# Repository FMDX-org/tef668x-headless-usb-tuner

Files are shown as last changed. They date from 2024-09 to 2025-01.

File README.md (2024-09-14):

# TEF668X Headless USB Tuner

USB radio tuner based on STM32F072 MCU and TEF6687 RF receiver with three antenna inputs and digital audio.

Copyright (C) 2024 FMDX.org

You may redistribute and modify this source under the terms of the CERN-OHL-W v2 (see LICENSE file).

# Credits 

- Konrad Kosmatka - HW & FW architecture and development
- Sjef Verhoeven - HW development
- Marek Kraus - HW & FW prototyping
- Marek Farkaš - testing and integration with FM-DX Webserver
- Przemysław Korpas - HW consultation, reviews
- Sebastian Białkowski - HW consultation, reviews

# Firmware

The firmware is available in a separate repository: [FM-DX-Tuner](https://github.com/kkonradpl/FM-DX-Tuner).

Firmware dependencies:
- Board: STM32 MCU Based Boards ([STM32duino](https://github.com/stm32duino)) - download using board manager
- Library: [TinyUSB](https://github.com/hathach/tinyusb) - install manually to the Arduino libraries

During first firmware flashing, short BOOT to 3.3V, plug the USB cable and flash using Arduino IDE (DFU method). Once the firmware is running, it is not necessary to manually short BOOT pin. See [tef-bootloader](https://github.com/kkonradpl/tef-bootloader).

# Audio output

The baseline version of the tuner supports only digital audio over USB. For a regular analog audio line-out, see the [Audiohat for Headless TEF](https://github.com/PE5PVB/Audiohat-Headless-TEF/).

# Important remarks

- TEF6687/V205 (F8705) chip is recommended for the best performance (FMSI, FULL SCAN RDS).
- RF circuits should contain NP0 (C0G) capacitors.
- Only V205 version of TEF668X supports the 55.46667 MHz crystal.
- For a crystal different than 55.46667 MHz, GPIO1 must be pulled to the ground (instead of pull-up).
- All capacitors and resistors are 0603, except R30 and R31 which are 0402.

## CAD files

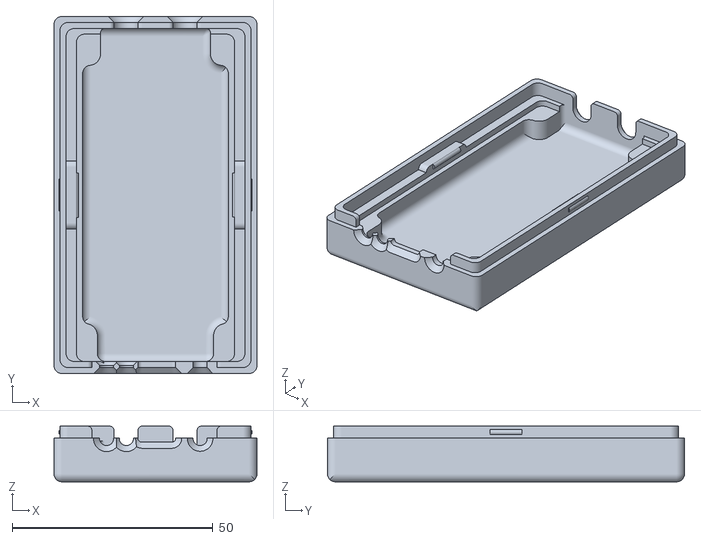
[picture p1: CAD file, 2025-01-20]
3d case/bottom.stl
50.5 x 88.8 x 13.9

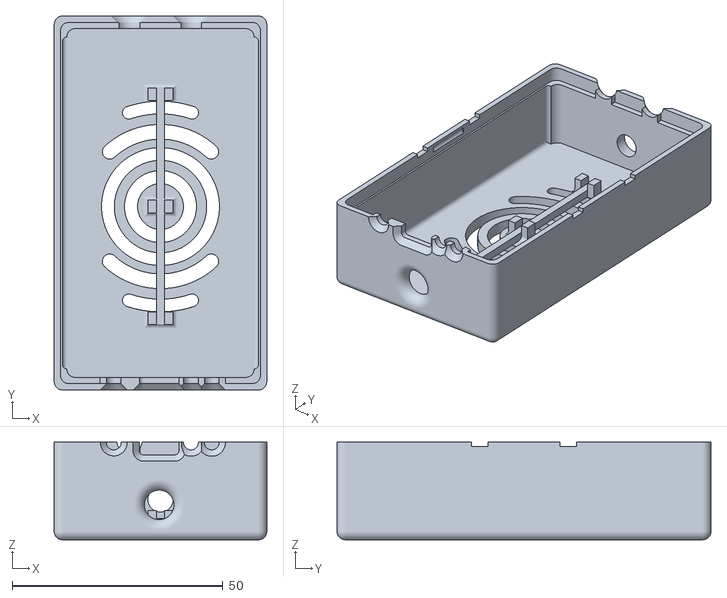
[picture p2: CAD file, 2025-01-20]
3d case/top.stl
50.5 x 88.8 x 23.2

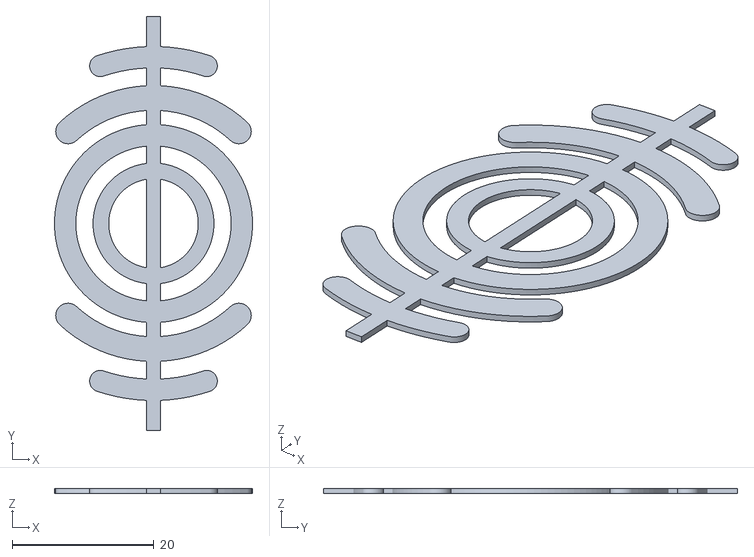
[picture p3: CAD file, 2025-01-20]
3d case/logo.stl
28.0 x 58.5 x 0.66

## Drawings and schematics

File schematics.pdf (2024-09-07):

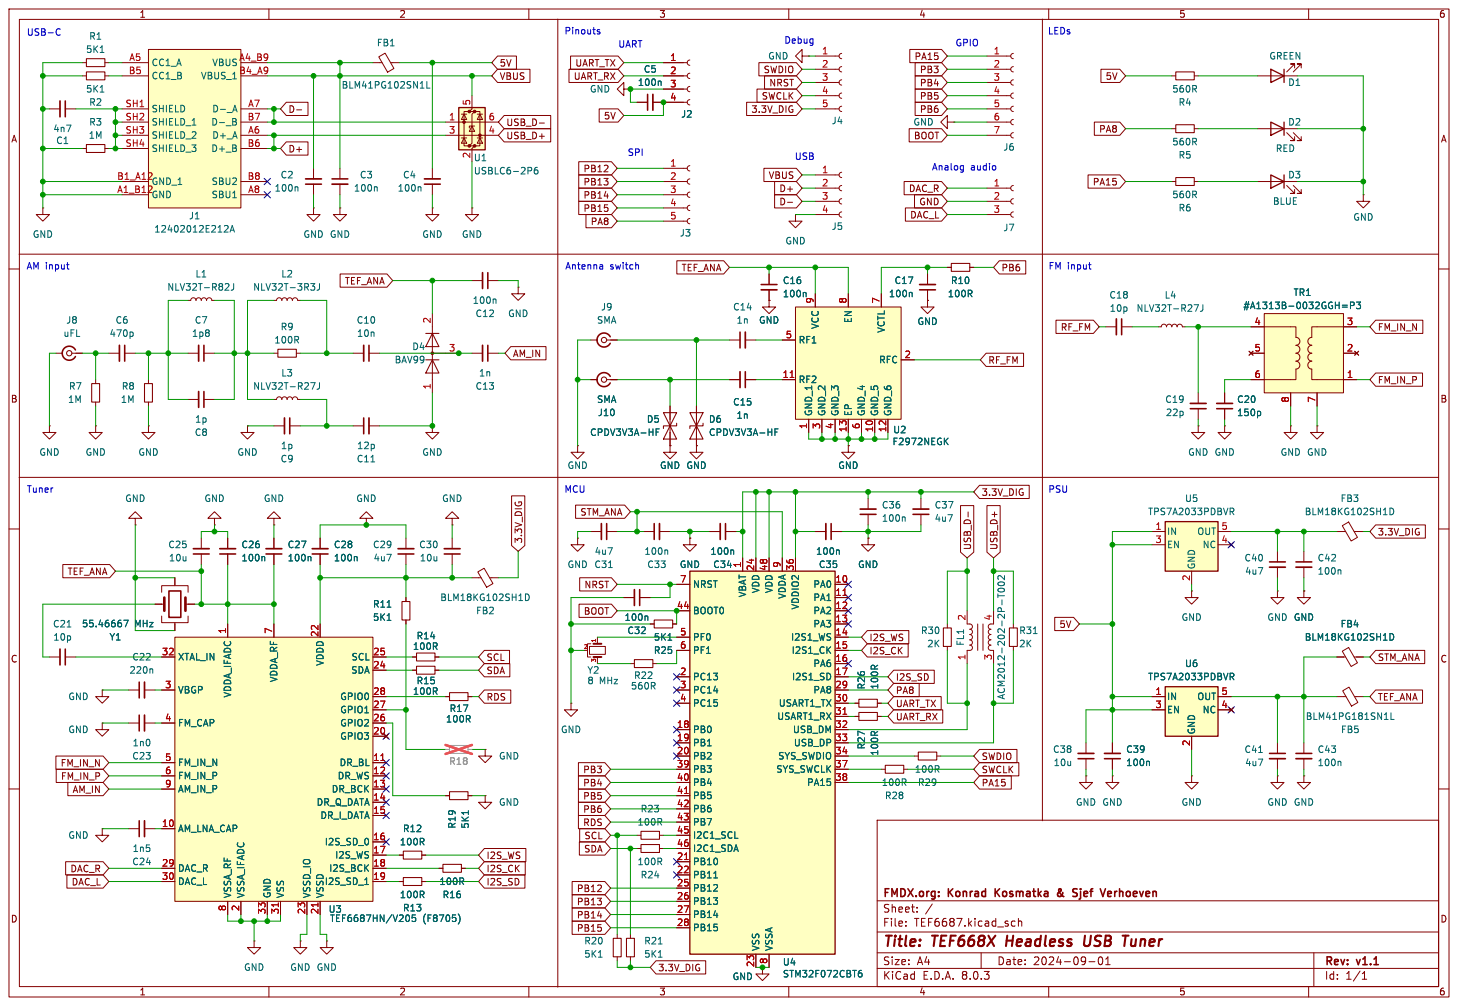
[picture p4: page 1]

2 EN 3 NC 4 OUT 5 U5 TPS7A2033PDBVR GND A1_B12 VBUS A4_B9 CC1_A A5 D+_A A6 D-_A A7 SBU1 A8 GND_1 B1_A12 VBUS_1 B4_A9 CC1_B B5 D+_B B6 D-_B B7 SBU2 B8 SHIELD SH1 SHIELD_1 SH2 SHIELD_2 SH3 SHIELD_3 SH4

2 GPIO3 20 VSSD 21 VDDD 22 VSSD_IO 23 SDA 24 SCL 25 GPIO2 26 GPIO1 27 GPIO0 28 DAC_R 29 VBGP 3 DAC_L 30 VSS 31 XTAL_IN 32 GND 33 FM_CAP 4 FM_IN_P 6 VDDA_RF

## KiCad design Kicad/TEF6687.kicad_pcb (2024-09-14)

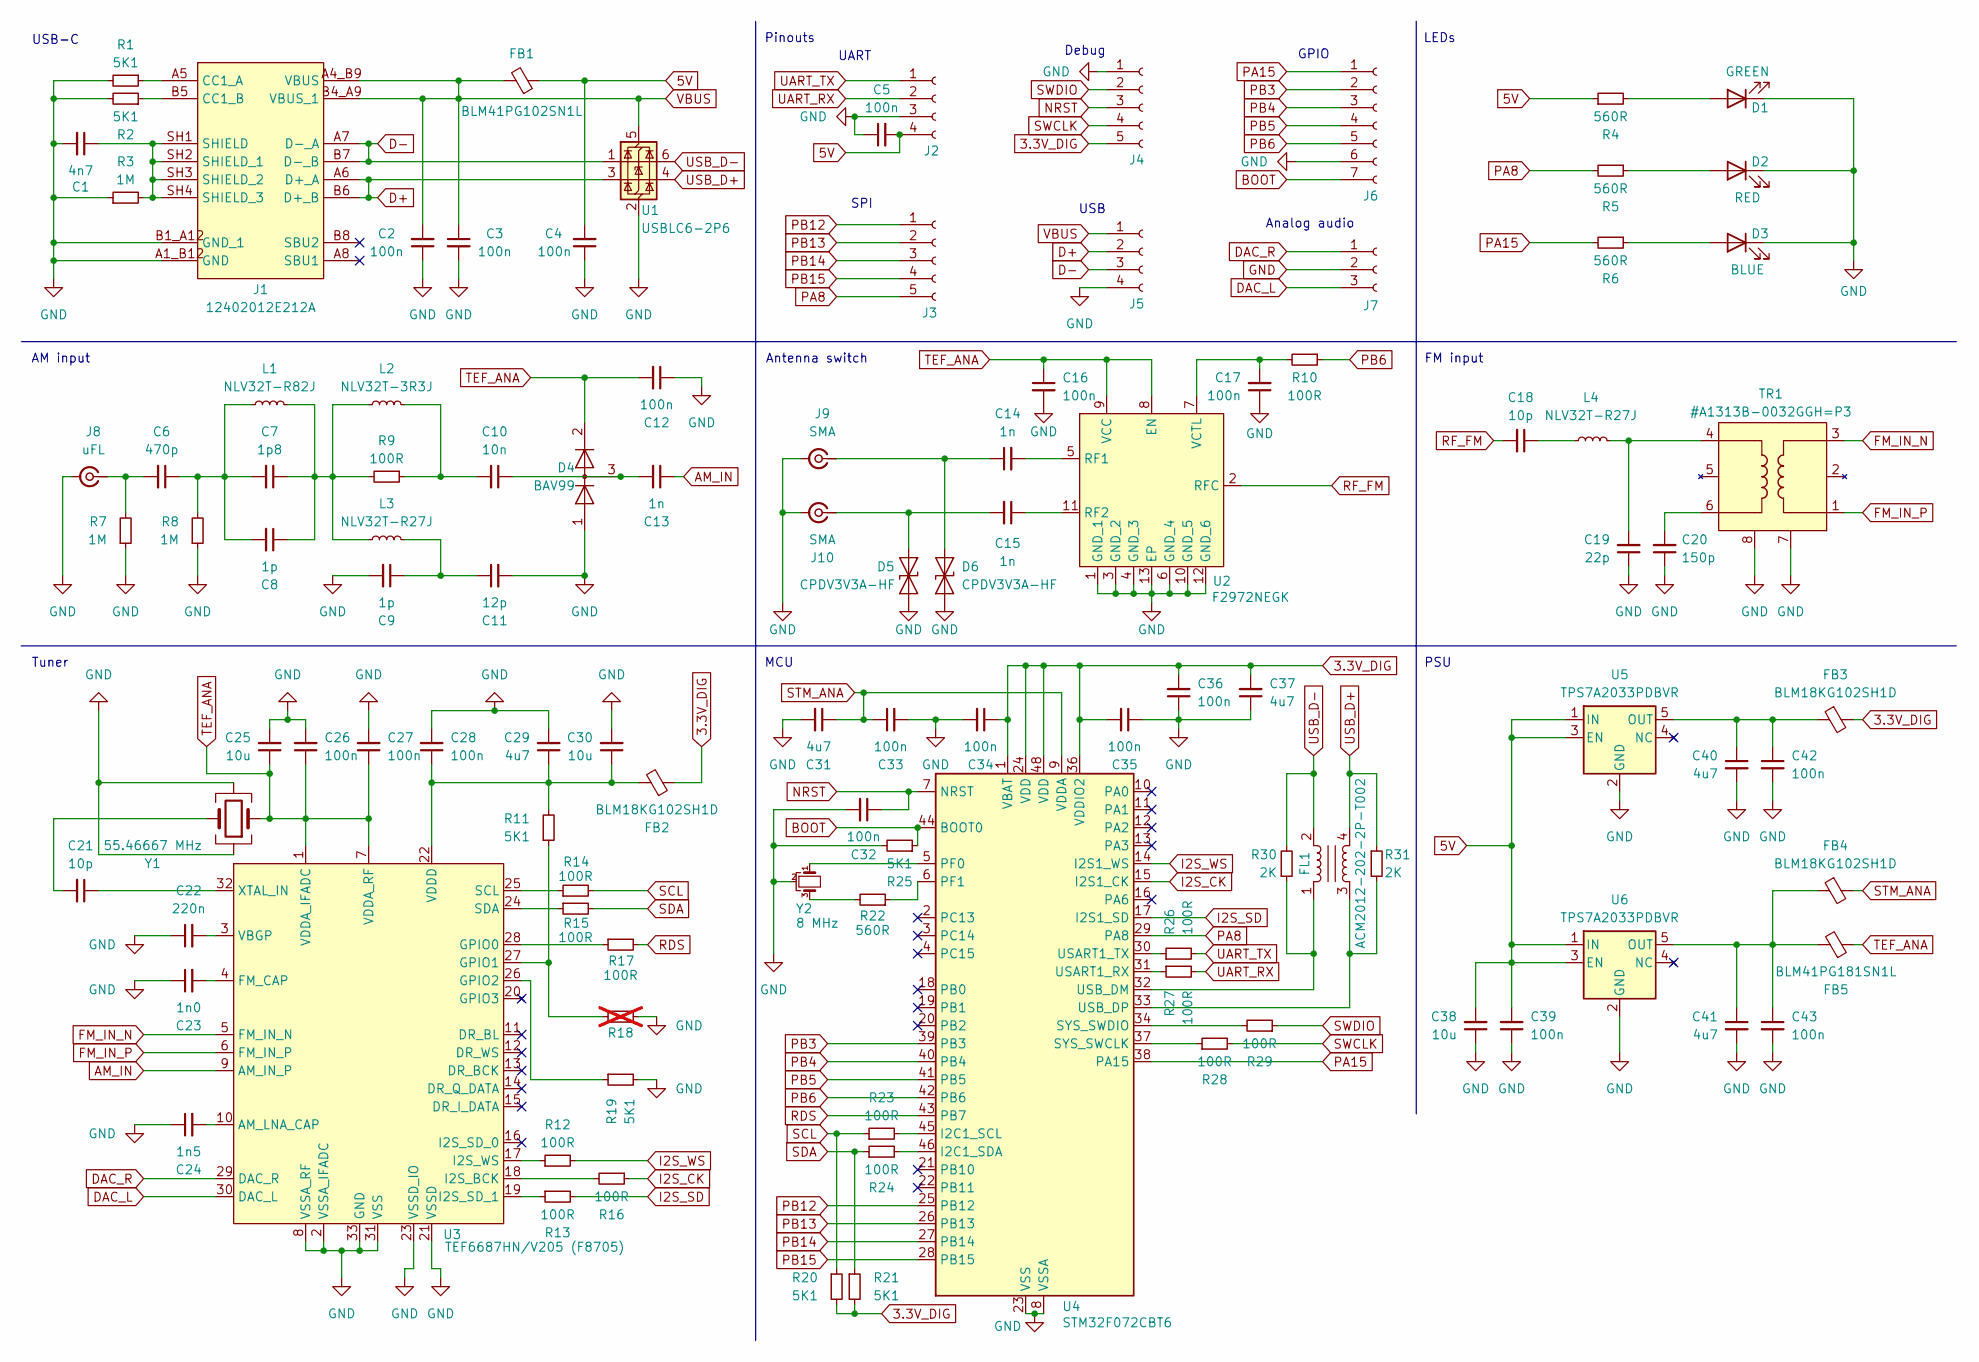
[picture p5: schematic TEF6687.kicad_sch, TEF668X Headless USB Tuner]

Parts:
C1: 4n7; C_0603_1608Metric
C2, C3, C4, C5, C12, C16, C17, C26, C27, C28, C32, C33, C34, C35, C36, C39, C42, C43: 100n; C_0603_1608Metric
C6: 470p; C_0603_1608Metric
C7: 1p8; C_0603_1608Metric
C8, C9: 1p; C_0603_1608Metric
C10: 10n; C_0603_1608Metric
C11: 12p; C_0603_1608Metric
C13, C14, C15: 1n; C_0603_1608Metric
C18, C21: 10p; C_0603_1608Metric
C19: 22p; C_0603_1608Metric
C20: 150p; C_0603_1608Metric
C22: 220n; C_0603_1608Metric
C23: 1n0; C_0603_1608Metric
C24: 1n5; C_0603_1608Metric
C25, C30, C38: 10u; C_0603_1608Metric
C29, C31, C37, C40, C41: 4u7; C_0603_1608Metric
D1: GREEN; LED_D1.8mm_W3.3mm_H2.4mm
D2: RED; LED_D1.8mm_W3.3mm_H2.4mm
D3: BLUE; LED_D1.8mm_W3.3mm_H2.4mm
D4: BAV99; SOT-23
D5, D6: CPDV3V3A-HF; D_SOD-323_HandSoldering
FB1: BLM41PG102SN1L; L_1806_4516Metric
FB2, FB3, FB4: BLM18KG102SH1D; L_0603_1608Metric
FB5: BLM41PG181SN1L; L_1806_4516Metric
FL1: ACM2012-202-2P-T002; USB_Filter_0805
J1: 12402012E212A
J2: 1x4; PinSocket_1x04_P2.54mm_Vertical
J3, J4: 1x5; PinSocket_1x05_P2.54mm_Vertical
J5: 1x4; JST_PH_S4B-PH-SM4-TB_1x04-1MP_P2.00mm_Horizontal
J6: 1x7; PinSocket_1x07_P2.54mm_Vertical
J7: 1x3; PinSocket_1x03_P2.54mm_Vertical
J8: uFL; U.FL_Molex_MCRF_73412-0110_Vertical
J9, J10: SMA; SMA_Molex_73251-2120_EdgeMount_Horizontal
L1: NLV32T-R82J; L_TDK_NLV32_3.2x2.5mm
L2: NLV32T-3R3J; L_TDK_NLV32_3.2x2.5mm
L3, L4: NLV32T-R27J; L_TDK_NLV32_3.2x2.5mm
R1, R2, R11, R19, R20, R21, R25: 5K1; R_0603_1608Metric
R3, R7, R8: 1M; R_0603_1608Metric
R4, R5, R6, R22: 560R; R_0603_1608Metric
R9, R10, R12, R13, R14, R15, R16, R17, R23, R24, R26, R27, R28, R29: 100R; R_0603_1608Metric
R18: 5K1 (only place when other crystal is used!); R_0603_1608Metric; not fitted
R30, R31: 2K; R_0402_1005Metric
TR1: #A1313B-0032GGH=P3; RF_Transformer
U1: USBLC6-2P6; SOT-666
U2: F2972NEGK; QFN_RF_Switch
U3: TEF6687HN/V205 (F8705); TEF668x
U4: STM32F072CBT6; LQFP-48_7x7mm_P0.5mm
U5, U6: TPS7A2033PDBVR; SOT-23-5
Y1: 55.46667 MHz; Crystal_SMD_3225-4Pin_3.2x2.5mm
Y2: 8 MHz; Resonator_SMD_Murata_CSTxExxV-3Pin_3.0x1.1mm

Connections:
3.3V_DIG: C34.1, C35.2, C36.2, C37.2, FB2.1, FB3.2, J4.5, R20.2, R21.2, U4.1 (VBAT), U4.24 (VDD), U4.36 (VDDIO2), U4.48 (VDD)
5V: C4.2, C5.2, C38.2, C39.2, FB1.1, J2.4, R4.1, U5.1 (IN), U5.3 (EN), U6.1 (IN), U6.3 (EN)
AM_IN: C13.1, U3.9 (AM_IN_P)
BOOT: J6.7, R25.1, U4.44 (BOOT0)
D+: J1.A6 (D+_A), J1.B6 (D+_B), J5.2, U1.3 (I/O2)
D-: J1.A7 (D-_A), J1.B7 (D-_B), J5.3, U1.1 (I/O1)
DAC_L: J7.3, U3.30 (DAC_L)
DAC_R: J7.1, U3.29 (DAC_R)
FM_IN_N: TR1.3, U3.5 (FM_IN_N)
FM_IN_P: TR1.1, U3.6 (FM_IN_P)
GND: C1.2, C2.1, C3.2, C4.1, C5.1, C9.2, C11.2, C12.1, C16.2, C17.1, C19.1, C20.1, C22.1, C23.1, C24.1, C25.2, C26.2, C27.2, C28.2, C29.2, C30.2, C31.2, C32.2, C33.2, C34.2, C35.1, C36.1, C37.1, C38.1, C39.1, C40.2, C41.2, C42.2, C43.2, D1.1 (K), D2.1 (K), D3.1 (K), D4.1 (K), D5.2 (A2), D6.2 (A2), J1.A1_B12 (GND), J1.B1_A12 (GND_1), J2.3, J4.1, J5.4, J6.6, J7.2, J8.2 (Ext), J9.2 (Ext), J10.2 (Ext), R1.2, R2.2, R3.1, R7.1, R8.1, R18.2, R19.2, R25.2, TR1.7, TR1.8, U1.2 (GND), U2.1 (GND_1), U2.3 (GND_2), U2.4 (GND_3), U2.6 (GND_4), U2.10 (GND_5), U2.12 (GND_6), U2.13 (EP), U3.2 (VSSA_IFADC), U3.8 (VSSA_RF), U3.21 (VSSD), U3.23 (VSSD_IO), U3.31 (VSS), U3.33 (GND), U4.8 (VSSA), U4.23 (VSS), U4.35 (VSS), U4.47 (VSS), U5.2 (GND), U6.2 (GND), Y1.2, Y1.4, Y2.2
I2S_CK: R16.1, U4.15 (I2S1_CK)
I2S_SD: R13.2, U4.17 (I2S1_SD)
I2S_WS: R12.2, U4.14 (I2S1_WS)
NRST: C32.1, J4.3, U4.7 (NRST)
unnamed: C6.1, C7.2, C8.2, L1.1, R8.2
unnamed: C7.1, C8.1, L1.2, L2.1, L3.1, R9.2
unnamed: C10.1, C13.2, D4.3 (K)
unnamed: C10.2, L2.2, R9.1
unnamed: C9.1, C11.1, L3.2
unnamed: C18.1, L4.1
unnamed: C19.2, L4.2, TR1.4
unnamed: C20.2, TR1.6
unnamed: C21.2, Y1.3
unnamed: D1.2 (A), R4.2
unnamed: D2.2 (A), R5.1
unnamed: D3.2 (A), R6.1
unnamed: C15.2, D5.1 (A1), J10.1 (In)
unnamed: C14.1, D6.1 (A1), J9.1 (In)
unnamed: J1.A5 (CC1_A), R1.1
unnamed: J1.B5 (CC1_B), R2.1
unnamed: C1.1, J1.SH1 (SHIELD), J1.SH2 (SHIELD_1), J1.SH3 (SHIELD_2), J1.SH4 (SHIELD_3), R3.2
unnamed: C6.2, J8.1 (In), R7.2
unnamed: R22.2, Y2.3
unnamed: C14.2, U2.5 (RF1)
unnamed: C15.1, U2.11 (RF2)
unnamed: C17.2, R10.2, U2.7 (VCTL)
unnamed: C24.2, U3.10 (AM_LNA_CAP)
unnamed: C23.2, U3.4 (FM_CAP)
unnamed: R17.1, U3.28 (GPIO0)
unnamed: R11.1, R18.1, U3.27 (GPIO1)
unnamed: R19.1, U3.26 (GPIO2)
unnamed: R16.2, U3.18 (I2S_BCK)
unnamed: R13.1, U3.19 (I2S_SD_1)
unnamed: R12.1, U3.17 (I2S_WS)
unnamed: R14.1, U3.25 (SCL)
unnamed: R15.1, U3.24 (SDA)
unnamed: C22.2, U3.3 (VBGP)
unnamed: C28.1, C29.1, C30.1, FB2.2, R11.2, U3.22 (VDDD)
unnamed: C21.1, U3.32 (XTAL_IN)
unnamed: R26.1, U4.30 (USART1_TX)
unnamed: R27.1, U4.31 (USART1_RX)
unnamed: FL1.1, R30.1, U4.32 (USB_DM)
unnamed: FL1.3, R31.2, U4.33 (USB_DP)
unnamed: R29.2, U4.34 (SYS_SWDIO)
unnamed: R28.1, U4.37 (SYS_SWCLK)
unnamed: R23.2, U4.45 (I2C1_SCL)
unnamed: R24.2, U4.46 (I2C1_SDA)
unnamed: U4.5 (PF0), Y2.1
unnamed: R22.1, U4.6 (PF1)
unnamed: C40.1, C42.1, FB3.1, U5.5 (OUT)
unnamed: C41.1, C43.1, FB4.1, FB5.2, U6.5 (OUT)
PA8: J3.5, R5.2, U4.29 (PA8)
PA15: J6.1, R6.2, U4.38 (PA15)
PB3: J6.2, U4.39 (PB3)
PB4: J6.3, U4.40 (PB4)
PB5: J6.4, U4.41 (PB5)
PB6: J6.5, R10.1, U4.42 (PB6)
PB12: J3.1, U4.25 (PB12)
PB13: J3.2, U4.26 (PB13)
PB14: J3.3, U4.27 (PB14)
PB15: J3.4, U4.28 (PB15)
RDS: R17.2, U4.43 (PB7)
RF_FM: C18.2, U2.2 (RFC)
SCL: R14.2, R20.1, R23.1
SDA: R15.2, R21.1, R24.1
STM_ANA: C31.1, C33.1, FB4.2, U4.9 (VDDA)
SWCLK: J4.4, R28.2
SWDIO: J4.2, R29.1
TEF_ANA: C12.2, C16.1, C25.1, C26.1, C27.1, D4.2 (A), FB5.1, U2.8 (EN), U2.9 (VCC), U3.1 (VDDA_IFADC), U3.7 (VDDA_RF), Y1.1
UART_RX: J2.2, R27.2
UART_TX: J2.1, R26.2
USB_D+: FL1.4, R31.1, U1.4 (I/O2)
USB_D-: FL1.2, R30.2, U1.6 (I/O1)
VBUS: C2.2, C3.1, FB1.2, J1.A4_B9 (VBUS), J1.B4_A9 (VBUS_1), J5.1, U1.5 (VBUS)

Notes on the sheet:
PSU
Pinouts
USB
AM input
GPIO
Antenna switch
Analog audio
MCU
UART
Tuner
USB-C
Debug
FM input
SPI
LEDs

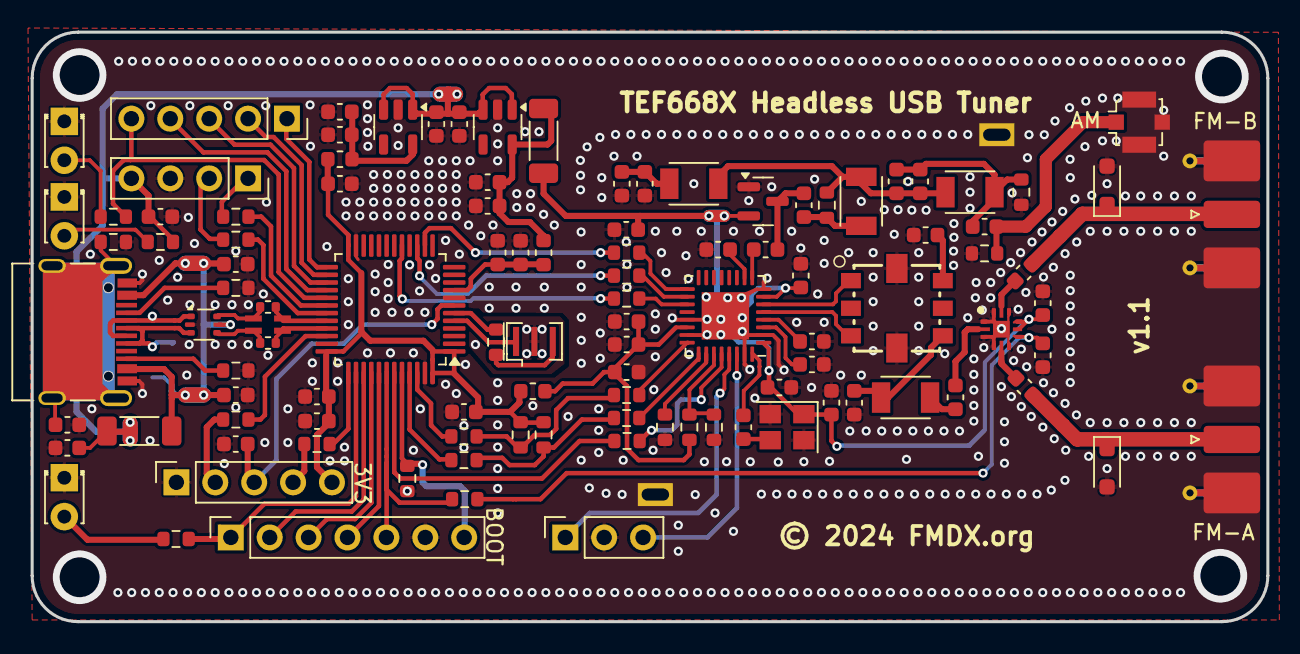
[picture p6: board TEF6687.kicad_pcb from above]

Board: 2 copper layers, 80.7 x 38.5 mm, 109 parts (1 on the bottom side), 85 nets.

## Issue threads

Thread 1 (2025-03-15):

MCU change to STM32F103CBT6 or FCM32F103CBT6

kawalkQCWski, 2025-03-15:
Use cheaper and faster controller FCM32F103CBT6 for less than $1  instead of F072 for more than $4 .

gamelaster, 2025-03-15:
Using Chinese clones of STM32 often leads to serious bugs and problems, such as problematic DFU, or weird IP cores quirks. It's not always good to use them, without a lot of testing.

About the STM32F103CBT6 you suggested, it even does not have I2S which is mandatory for this project.

There are various STM32 chips which would be suitable, but the price would be mostly same. It's important to have proper I2S Master peripheral (with external clock), and the chip must be supported by both Arduino Core for STM32 and TinyUSB.

kkonradpl, 2025-03-16:
@gamelaster explained it very well.

I can only add that the cost of F072 is much lower, even at low qty (Mouser, Qty 10+: $2.61). You can also save $0.2 by dropping the 8 MHz ceramic resonator, because F072 supports crystal-less USB operation, which has been proven to be reliable.

kawalkQCWski, 2025-03-16:
thanks for the explanation . lets close the issue

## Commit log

2024-09-07 Add schematics
2024-09-14 Final release
    [TEF6687.kicad_pcb, TEF6687.kicad_sch]
2024-09-14 Update README and add BOM
2024-11-17 Added gerbers
    [TEF6687-B_Courtyard.gbr, TEF6687-B_Cu.gbl, TEF6687-B_Fab.gbr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]
2024-11-17 Added 3d case
    [usb tef.3mf]
2025-01-20 Update 3d model to STL files
    [bottom.stl, logo.stl, top.stl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]

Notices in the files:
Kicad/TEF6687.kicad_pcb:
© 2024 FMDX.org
